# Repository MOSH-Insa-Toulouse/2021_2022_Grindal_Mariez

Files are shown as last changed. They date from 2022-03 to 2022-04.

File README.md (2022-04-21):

2021_2022_Grindal_Mariez_graphite_flex_sensor_project

# Objective of the project
The objective of the project is to design and build a PCB shield including a **low-tech graphite strain sensor** coupled to an analog electronic circuit that communicates data via a microcontroller to an Android application. The aim of this project is to get the resistance from a graphite sensor to measure a deformation, to analyze the results obtained and to describe the characteristics of the sensor in a datasheet.

# Main steps of the project
   [1. Graphite sensor conception](#1-graphite-sensor-conception)\
   [2. Electrical conception and simulation on *LTSpice*](#2-electronic-conception-and-test-on-ltspice)\
   [3. PCB conception and printing](#3-pcb-conception-on-kicad)\
   [4. Arduino code](#4-arduino-code)\
   [5. Application ANDROID](#5-apk-application)\
   [6. Test bed](#6-test-bed)\
   [7. Datasheet](#7-datasheet)\
   [8. Limits](#8-limits)

# 1. Graphite sensor conception
The first step is to make the graphite sensor with paper and a pencil. Pencil cores and lead mines used in mechanical pencils consist of a mixture clay and tiny scales of graphite that can slide on top of each other. The sensor outline is printed on a piece of thick printing paper, and the remaining work is simply to cut it out and fill in the dotted "U" shape with a pencil, as shown on the image below. 
<p align="center"> 
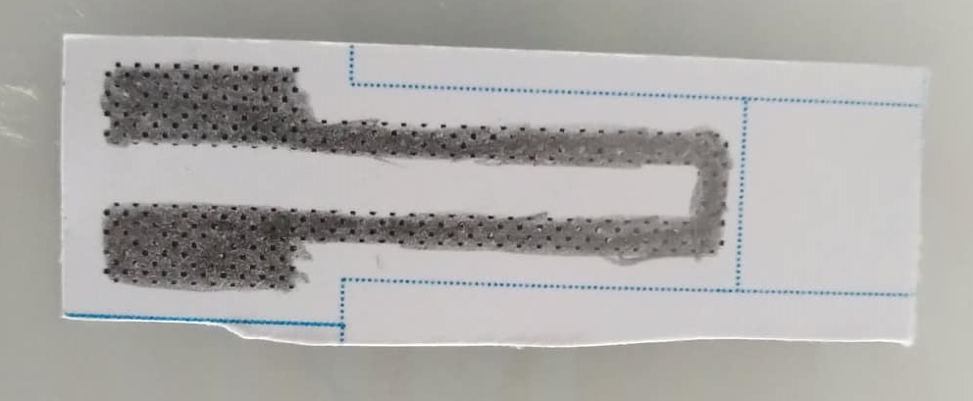
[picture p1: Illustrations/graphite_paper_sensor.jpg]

    
The upside is that is allows to adjust the amount of graphite by adding or erasing the pencil mark containing graphite. The downside is the difficulty of reproducing the same sensor with the same graphite layer thickness and density of graphite. An additional problem regarding graphite is presented below.

<div align="center">    
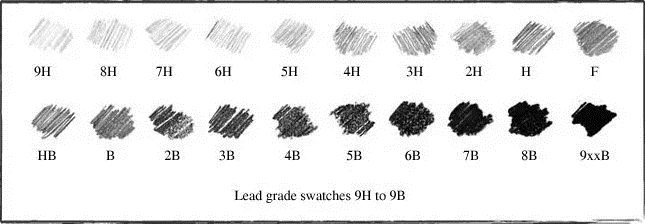
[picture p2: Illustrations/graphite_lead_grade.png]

   
**Graphite grading scale problem**
    
<div align="left"> 
    
There exists different graphite grading scales, with the numerical scale and the HB scale the two most widely used. The HB scale goes from 9B to 9H, “H” to indicate a hard pencil and “B” to designate the blackness of the pencil’s mark, indicating a softer lead and a higher proportion of graphite.
    
The problem when trying to reproduce a sensor is the lack of a specific industry standard for the darkness of the mark to be left within the HB or any other hardness grade scale. That implies that a HB pencil from one brand will not necessarily leave the same mark as a HB pencil from another brand. Most manufacturers set their own internal standards for graphite hardness grades and some differences are regional. For example in Japan, consumers tend to prefer softer darker leads, so an HB lead produced in Japan is generally softer and darker than an HB from European producers.
    
Specifying the exact product and manufacturer in addition to the graphite grading can increase the reproductibilty of the sensor.
> This project uses graphite from BIC Criterium 550 pencils with the gradings 6B, 4B, B, H and 3H. Special STEIN HB lead mines from Pentel is also used. STEIN stands for "Strongest Technology by Enhanced SiO2 Integrated Network" and have a 10 % denser core than an average HB lead mine. This can result in a different resistance range than a normal HB pencil despite applying it the same way with the same thickness etc.

# 2. Electronic conception and test on *LTSpice*
The second step is to build the electrical circuit adapted to our case. Strain sensor is a passive sensor and needs a conditionner. The output signal od the sensor is very low and can be easily interfered by noise (from the circuit or external noise). The aim of this part is to chose the good components to have the good filters and amplifiers. We also have to take into account the chracteritic of the arduino uno card we are gonna use:
* Resolution 10 to 12 bits (1024 à 4096 points)
* Full scale (VRef) : 1.1 V to 5.0 V
* Max source impedance 1 kOhm to 10 kOhm
* Max sampling frequency 15 kHz to 2.4 MHz
 
Graphite sensor is supplied by 5 V and gives resistance values between 20 MΩ and 100 MΩ. Direct measurement of a 100 nA current does not seem feasible. We have to amplifiy the signal and to filter it.
The final electrical circuit chosen is the following:
<p align="center">
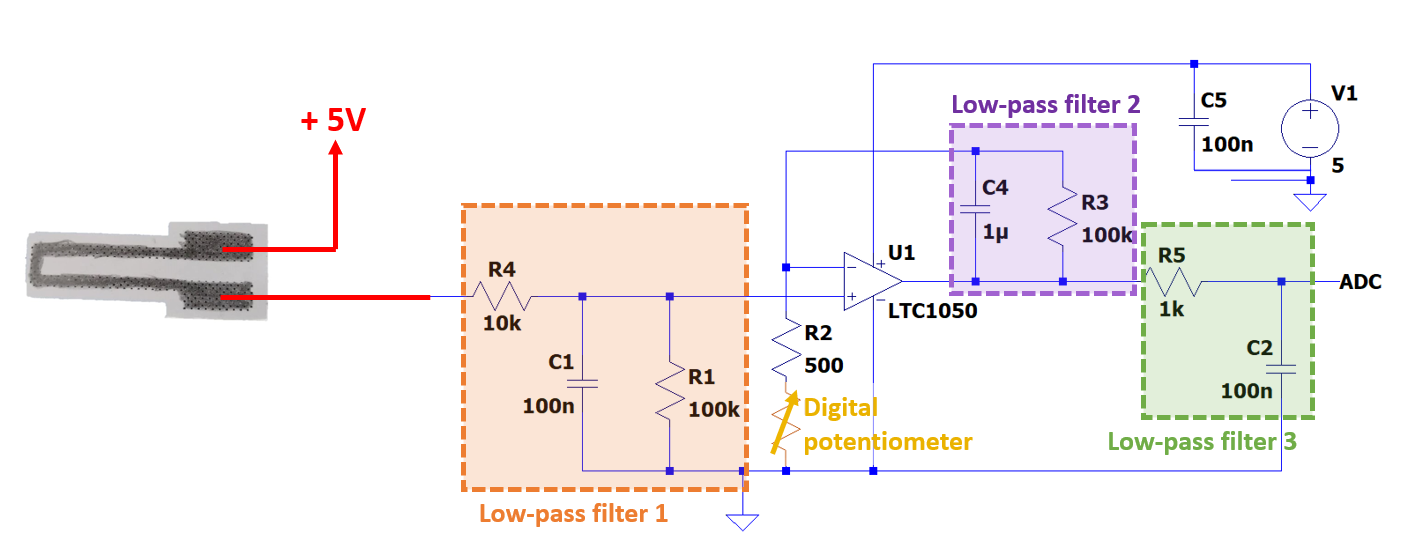
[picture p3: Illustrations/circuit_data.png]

 
### Role of different components:
> R5 at the input protects the operational amplifier against electrostatic discharges (ESD), and together with C1 makes up a filter for voltage noises
> 
> C1 with R1 makes up a filter for the current noise
>
> R2 is replaceable, in order to allow an adaptaion of the full scale range (digital potentiometer)
>
> C4 with R3 makes up the active filter
>   
> C2 with R6 makes up the passive output filter
>   
> C3 filters out the power supply noise
>   
> The digital potentiometer MCP41050 can change the gain and adapt it to the resistance value from the graphite sensor. Resistance of the digital potentiometer can vary between 330 Ω and 50k Ω based on datasheet. 
 
### Sensor resistance calculation:
<p align="center">
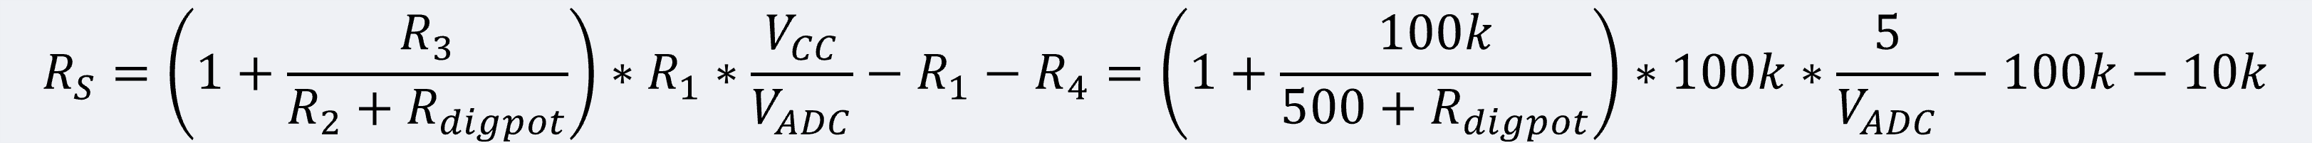
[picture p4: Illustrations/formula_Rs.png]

 
### Low-pass filters
> For each electrical stage, we can simulate the cuttoff frequency by putting the capacity of each filter at zero:
> * Low-pass filter 1 (C4 = C2 = 0) : 16 kHz\
>      To select signals with frequency less than 10*1.5kHz (sample frequency of the arduino card) to respect Shannon criteria
> * Low-pass filter 2 (C1 = C2 = 0) : 2,1 kHz\
>      To filter noises from sector of the power supply at 50 Hz
> * Low-pass filter 3 (C1 = C4 = 0) : 1,6 kHz\
       To filter global external noises of voltage and current
 
### Main characteristics of the electrical circuit
> Global gain: from 3.13 to 127.9
>
> Global attenuation of a 50 Hz current noise: 100 dB or 10e5
>
> Offset of the LTC1050 is about 5 µV wich is acceptable because much lower than the voltage measured to ouputs of the resistance R1 of 10 mV (and the maximum offset voltage drift is about 0.05 μV/°C).

### Simulations on *LTSpice*
> Simulations on LT-Spice allowed us to:
> * To check the operation in nominal conditions
> * To check the operation in nominal conditions
> * To accept the impact of the LTC1050C amplifier offset
> * To accept the impact of the amplifier input current
> * To find the cuttoff frequency of each low-pass filter stage
> * To find the global attenuation of a 50 Hz current noise
> * To find the global attenuation of a current noise occurring at the aliasing limit frequency
>
> To check all these points, we did differents simulations:
> * In transient conditions, with a pulse signal from the sensor
> * In AC conditions, to see attenuation, gain and cuttoff frequencies
> * In transient conditions, with AC voltage generator to simuate 50 Hz noise.
> * In transient and AC conditions with resistance of the digital potentiometer varying from 1 kΩ to 15 kΩ (step of 1 kΩ) to see the influence of this component on ccircuit response.
<div align="center"> 
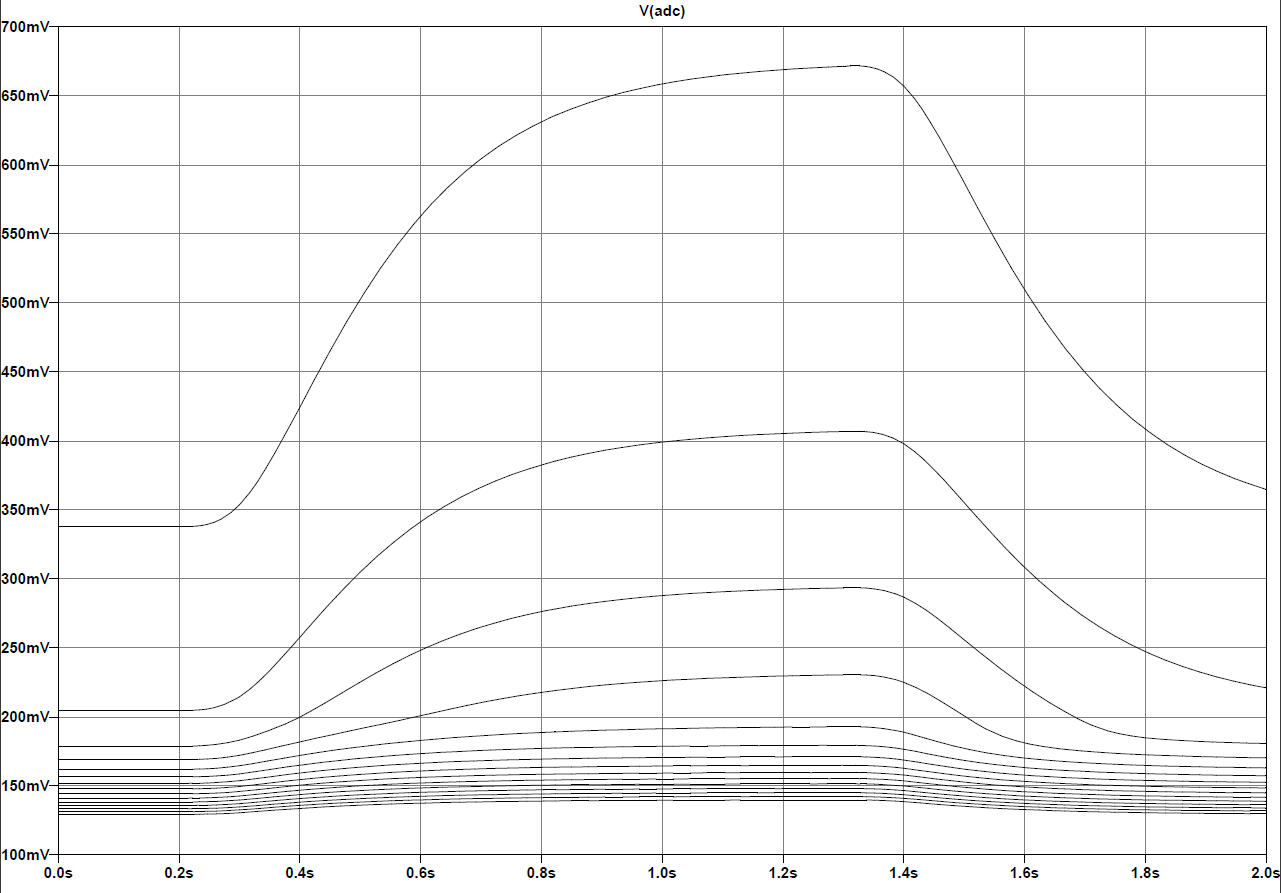
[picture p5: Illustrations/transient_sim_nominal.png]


**Transient simulation with R2 varying between 1 kΩ to 15 kΩ**
 
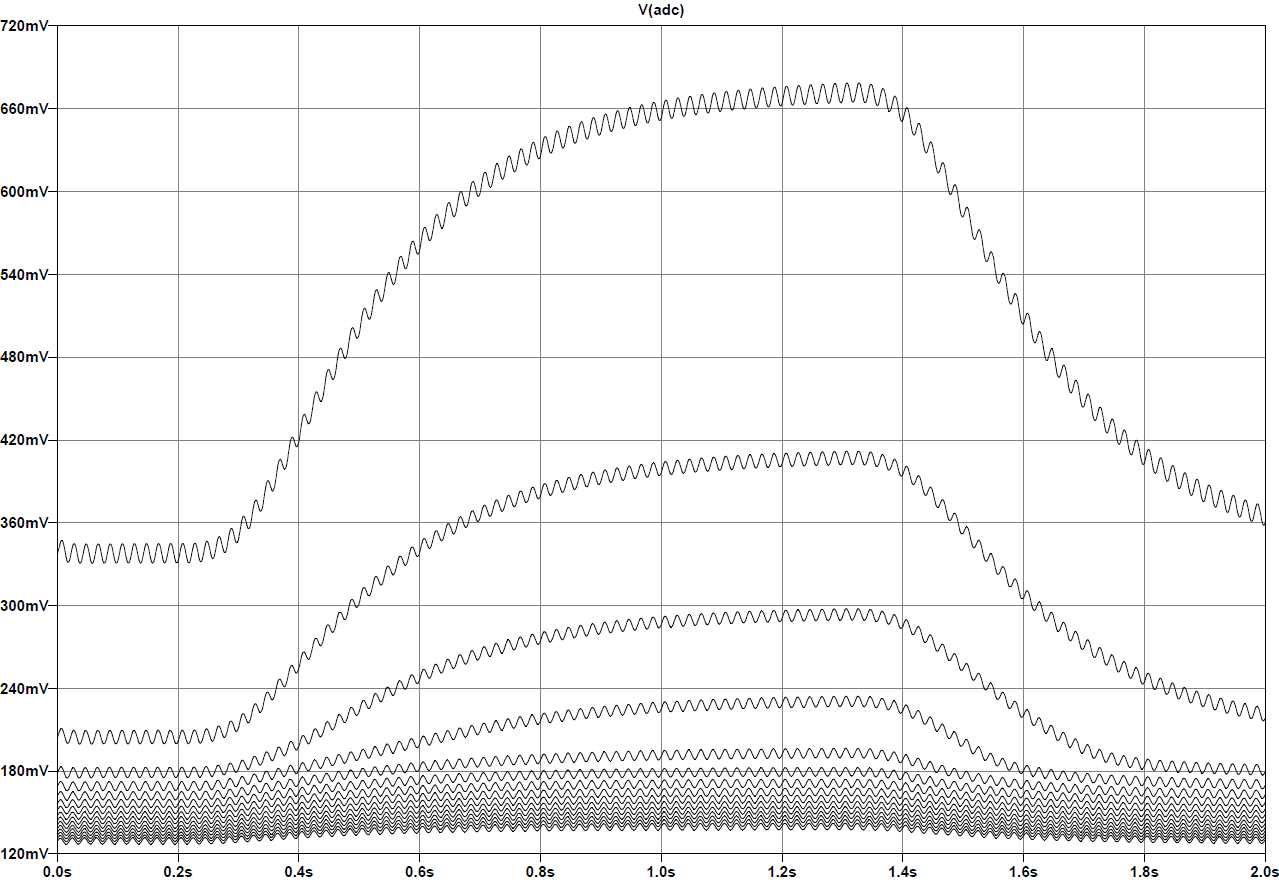
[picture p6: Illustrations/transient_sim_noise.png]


   **Transient simulation with with R2 varying between 1 kΩ to 15 kΩ and noise at 50 Hz (oscillations)**
   <div align="left">   

> The digital potentiometer has a strong influence on electrical circuit. The gain is modified, but not into a linear way with potentiometer variation. The more the resistance is high, the less is the gain, and the worse is the output signal (see [Limits](#8-limits) section)

The folder 
   [Electrical simulations on LT-Spice](https://github.com/MOSH-Insa-Toulouse/2021_2022_Grindal_Mariez/tree/main/Electrical%20simulations%20on%20LT-Spice) 
   contains the LT-Spice files used into different simulations. 

# 3. PCB conception on _KiCad_
Once the electrical circuit is done, we have to make the PCB conception to get the final circuit. First, we did the schematic in *KiCad*. Then, we build the PCB plane by adding the references and dimensions of each components. The final step is to print the PCB card with different processes.
Circuit conception was made on *KiCad*. 
### Circuit schematic on *KiCad*
> The electrical circuit was made in KiCad. All pins and connections are established. For each components, we have to associate the print. For LTC1050, rotary encoder, digital potentiometer and OLED screen, we have to create our own print in our own library. The schematic is made from a model with Arduino Uno shield to have directtly the right pins and the good dimensions of the card.
>  
<p align="center">
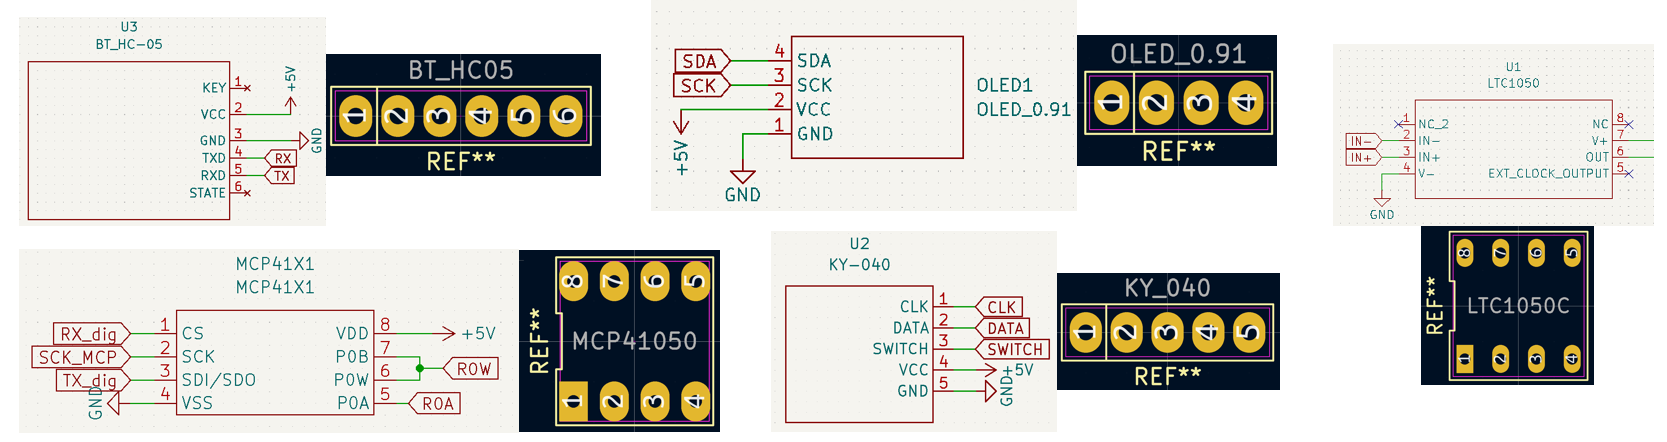
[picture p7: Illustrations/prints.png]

    
### PCB conception on _KiCad_
> After doing the schematic, we draw the PCB with the previous dimensions :
> * Track length = 0.9 mm
> * Isolation width = 0.7 mm
> * Pad dimensions for OLED, Bluetooth module and rotary encoder = 2 mm * 2.5 mm
> * Drill size for OLED, bluetooth module, rotary encoder, AOP and digital potentiometer = 1 mm
> * Pad size for AOP and digital potentiometer = 1.8 mm * 2.5 mm
> * Drill size for resistances and capacities = 2 mm
> * Pad size for resistances and capacities = 0.8 mm
> For each component, we have to find the print associated or to make it into a new libary (for rotary encoder, OLED screen, LTC1050 and digital potentiomter). After placing the components in the optimal way, we trace the wires and make the ground plane.
> 
<p align="center">
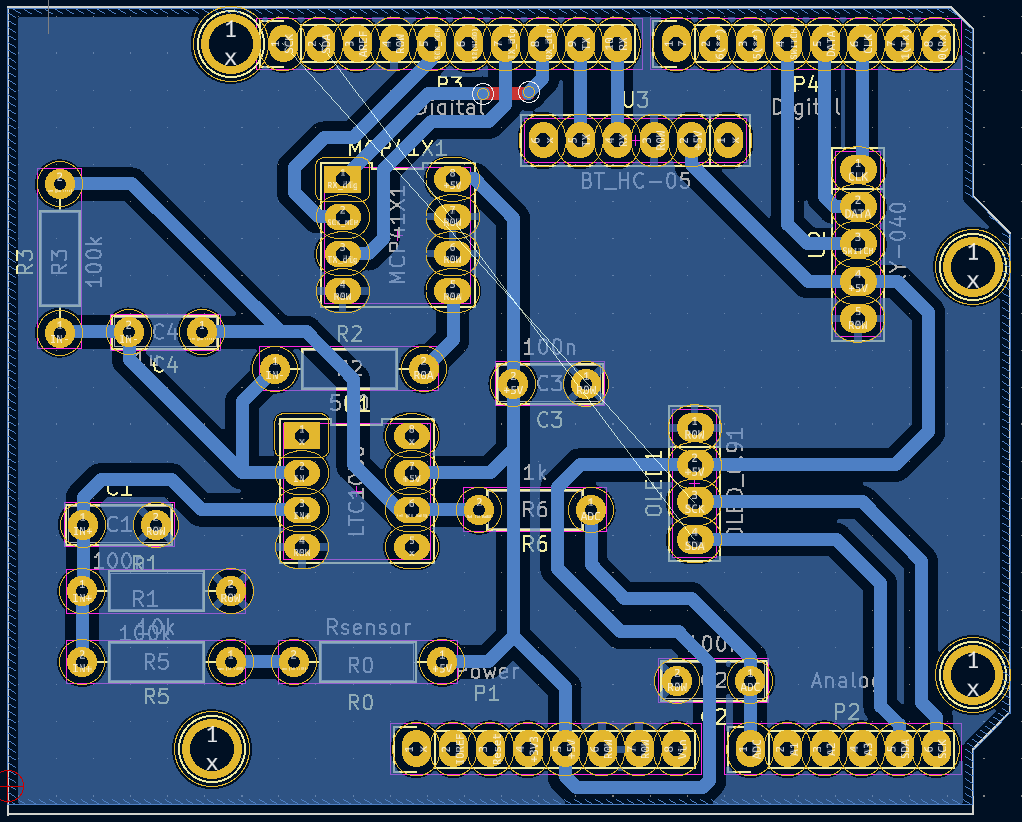
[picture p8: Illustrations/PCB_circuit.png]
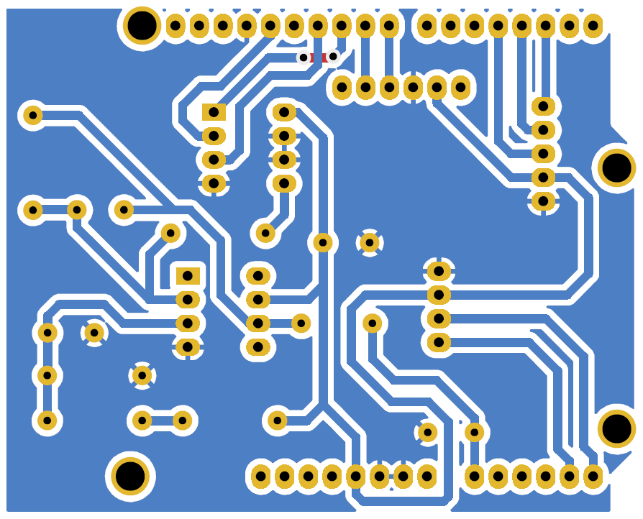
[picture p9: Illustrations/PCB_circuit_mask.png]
 

### PCB 3D visualisation  
> 
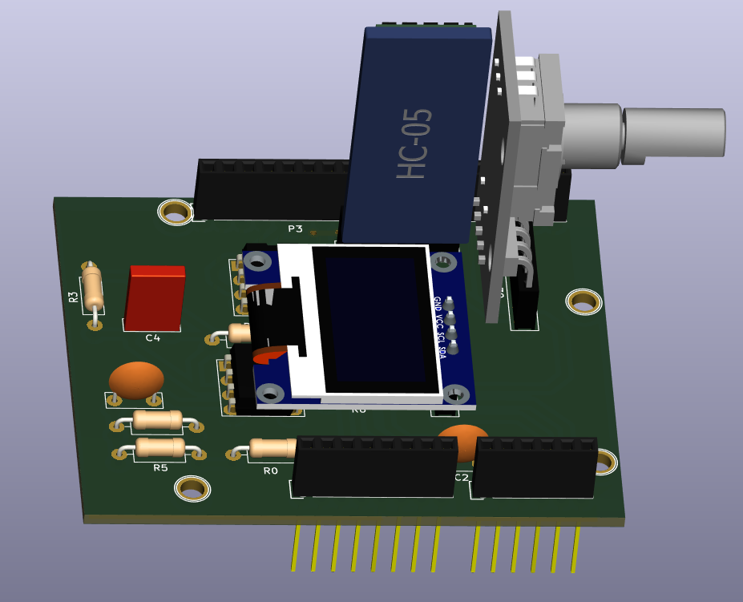
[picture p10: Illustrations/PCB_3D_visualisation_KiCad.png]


> A 3D visualisation is possible and allowed us to well arrange components placement without spatial conflict. 

All *KiCad* files are in the folder [Projet2022_grindal_mariez_pcb](https://github.com/MOSH-Insa-Toulouse/2021_2022_Grindal_Mariez/tree/main/Projet2022_grindal_mariez_pcb)
   section.

### PCB printing processes
> Mask printed on transparent film (PCB plan from KICAD) 
>
> The mask is placed on a plate of copper convered with photo-sensitive film. The mask and the plate are insolated with UV. The black part of the mask protects the photo-sensitive resin from UV, and the clear zone of the mask reveals copper beacause photo-sensitive resin reacts with UV.
>
> PCB plate is washed with a developper solution (oxydied water) that reveals the PCB circuit
>
> PCB plate is placed in oxyde bath to remove the unwanted copper not protected by photo-sensitive zone left.
>
> PCB is washed and left to dry.

<div align="center"> 
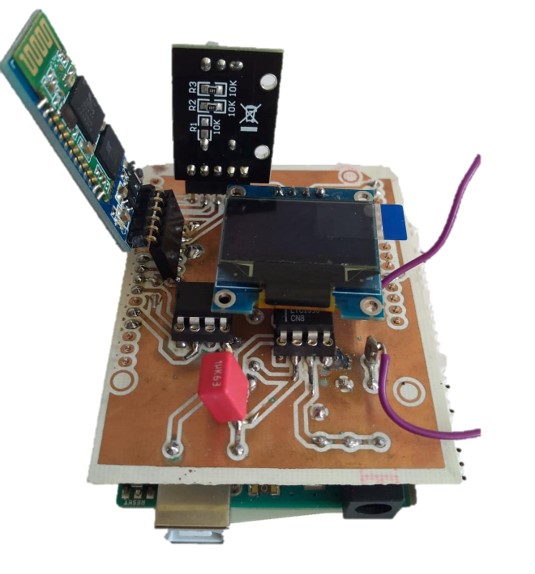
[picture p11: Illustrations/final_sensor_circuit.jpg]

   
**Final PCB circuit with all components and modules. The two wires (at right, in purple) are  \
   connected to the two pads of the graphite sensor with clamps.**
<div align="left"> 
    
# 4. Arduino code
### Improvement potential for Arduino code
> Make the code run faster and more smoothly by optimizing menu management code. This can be done by decreasing the lines of code for the OLED display and assure the switch button on the rotary encoder, which is not connected to an interrupt pin, is detected regardless of the speed of the executing loop.  The number of variables in use for the menu, submenu and blocking the rotary encoder when needed should be reduced. Suboptimal solutions to ensure the screen is refreshed correctly can be improved upon.
>
> Decrease the time interval between two measurements, currently at 700 ms, to see how fast it can measure and decrease response time.
    
### General structure of Arduino code
>The Arduino code (.ino) is written in C++ with an addition of special methods and functions.
The main text editing program used for this project is the Arduino Integrated Development Environment (IDE). It has a clean and simple interface with the option of showing a serial monitor and a serial plotter. The serial monitor is useful for checking the outcoming bytes from the board to the digital potentiometer MCP41050 and communication with the APK application via the Bluetooth module HC-05.
    
### Libraries used 
> SoftwareSerial.h for defining serial ports on specific pins, here used with the Bluetooth module and digital potentiometer.
>
> Adafruit_GFX.h and Adafruit_SSD1306.h for the I2C OLED display SBC-OLED01.
>
> Wire.h contain the definitions for I2C pins used to communicate with the OLED display.
>
> SPI.h is used to communicate with SPI devices, with Arduino as the master device. The Serial Peripheral Interface (SPI) is a synchronous serial data protocol and is used with the digital potentiometer.

### The Arduino code is divided into four parts:
>The first lines contain inclusions (#include) of libraries, definitions (#define), which is a C++ component that allows to give a name to a constant value before the program is compiled, and declarations of global variables.
>    
>The setup() function, which initializes and sets the initial values, is executed only one time after powering on the Arduino board. 
In this case, the mode of pins on the board are initialized with pinMode(), and digitalWrite() is used to turn on the pullup resistors for the rotary encoder KY-040. Data transfer through serial ports, SPI, SoftwareSerial and Serial, is enabled.
>    
>The loop() function is the main part and runs continuously after the setup until the reset button is pressed or the power supply is cut.
    It is far from optimized and contain a lot of if-statements. First it checks to detect a change in the switch button, then checks if the APK application has asked for measurement data or an updated Rcal value to update the gain. Then it does a measurement if the interval requirement is met. The last part of the loop is a mix of rotary encoder and OLED display to make the menu and submenu options work. 
>  
>The last part is constituted of definitions of the functions used in the loop function. Six functions are defined. 
>   * The first function reads the analog pin connected to the sensor called readSensor() and returns the voltage in the range 0–5 V. 
>   * Two functions manages the digital potentiometer, setPot() and potSwiper(). setPot() changes dig. pot. position and updates Rcal and gain. potSwiper() uses setPot() and takes a float as input, with the goal to land on approximately the right voltage by running through the positions to find an adequate resistance value. 
>   * The OLEDstartup() function is simply the startup screen sequence, lasting around two seconds.
>   * The last functions doEncoderA() and doEncoderB() is attached to interrupts on both pins for the rotary encoder and includes debouncing, ensuring a rapid and accurate response to manual rotation of the encoder. The variable maxRot ensures a circular list regardless of scrolling through the menu or manually adjusting the gain.

Arduino code is available in the [Arduino code](https://github.com/MOSH-Insa-Toulouse/2021_2022_Grindal_Mariez/tree/main/Arduino%20code)
   section.
  
# 5. APK application
The APK application, working on Android smartphones, is made with the free web application integrated development environment MIT App Inventor.The app communicates over Bluetooth with the HC-05 module mounted on the Arduino shield, and allows to measure and trace resistance and voltage over time.
Main features:
* Display measured voltage and resistance numerically and traced as a function of time
* Update gain if modified on the shield
* Save measured data points in a text file found in the paths "/savedRfile.txt" and "/savedVfile.txt"
    
<p align="center"> 
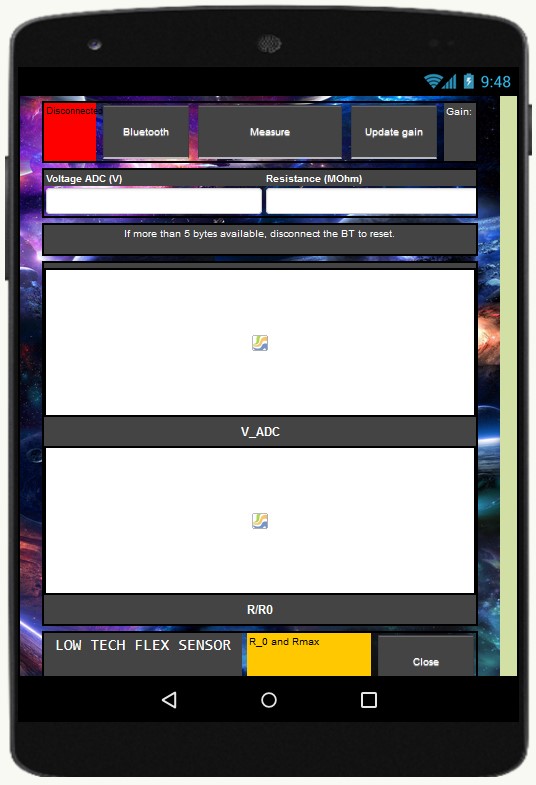
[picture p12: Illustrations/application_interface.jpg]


The application folders .apk and .api are  available in the [Application](https://github.com/MOSH-Insa-Toulouse/2021_2022_Grindal_Mariez/tree/main/Application)
   folder.
 
# 6. Test bed
The six sensors were tested under compressive and tensile deflection on cylindrical objects with a constant diameter. The test bed consisted of seven cylindral objects with each a diameter ranging from 7 cm to 1,15 cm. The contact surface was covered in paper to minimize interactions between the object and the graphite layer on the sensor under compressive deflection.

### Test procedure
> The sensor was connected to the shield with two alligator clips. Voltage measurements indicated if the start voltage was near the extreme values of the range 0-5 V, indicating signal saturation in case of very high voltage and no current flowing in case of 0 V. Saturation of the signal was handled by choosing the "set gain" option in the menu to automatically adjust the gain to start at around 1 V. No signal was fixed by applying more graphite on the dotted area of the sensor.
>
> The R0 at zero derformation was measured when the sensor was pressed flat.
>
> Each sensor was first tested under tensile deflection, that is the graphite facing away from the curvature, with the assumption that the compressive deflection is more damaging to the sensor. The tensile deflection increases the distance between the graphite layers and decreases the measured voltage. The measurements were done in the order of decreasing diameter, starting with the smallest deformation to bend the paper sensor as little as possible to avoid detoriation.
>
> Graphite was reapplied on top of the old layer and a new R0 was measured when pressed flat.
> The same procedure was repeated for the compressive deflection with the sensor laying on a flat surface graphite layer up and bent upwards around the object while pressing the object gently downwards close to the edge of the table where the alligator clips were aligned. To avoid smearing of the graphite layer, especially for the 4B and 6B pencils, minimal friction was ensured between the sensor and the paper covered object. It is possible that smearing would have a minimal impact because the layer applied was thick. The measurements were done in the order of decreasing diameter, starting with the smallest deformation. 
>
> For compressive deflection, sudden drops in voltages occured for some of the sensors when repedately bending around the smallest objects and inducing large deformations. In those cases, graphite was reapplied on top of the old layer, a new R0 was measured when pressed flat and a new measurement series was conducted starting with the largest object.
    
# 7. Datasheet
Datesheet is providing the main characteristics and technical specifications of the strain sensor. It is in the folder [Datasheet](https://github.com/MOSH-Insa-Toulouse/2021_2022_Grindal_Mariez/tree/main/Datasheet)
   of the repository. 

# 8. Limits
   Is important to notice the limits of the sensor and the innacuracy of the test measures. Here are main points to be studied or solved:
   * The digital potentiometer MCP41050 is perfectly adapted to the graphite sensor. It would be better to have a sensor with a resistance variation between 10 Ω to 15 Ω, as the MCP41010 from *Microchip* for example.
   * The mapping from 8 bits to 10 bits in arduino code may lead to a resolution loss, so we lose in quality for the signal. 
   * We need a switch button to interrupt in case of problems
   * Regarding test bed, we are never sure of the amount of deposited graphite and it is not uniform. Also, the graphite quantity variation is not linear with pencils changing. Finally, paper is damaged after several compression/tension, so the measures are never similar

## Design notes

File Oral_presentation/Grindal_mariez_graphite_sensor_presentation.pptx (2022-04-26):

## Capteur de déformation low-tech

GRINDAL Ruth E.
MARIEZ Edith
INSA TOULOUSE – Génie Physique

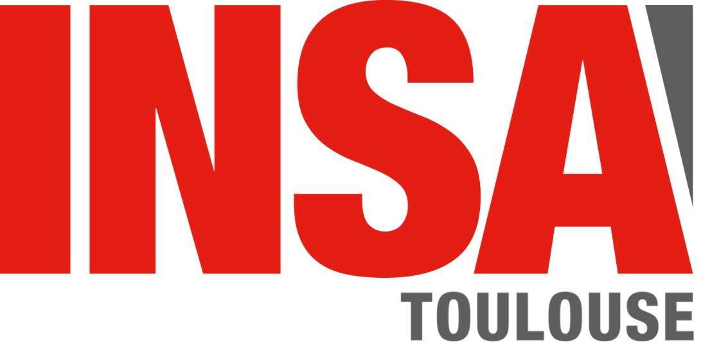
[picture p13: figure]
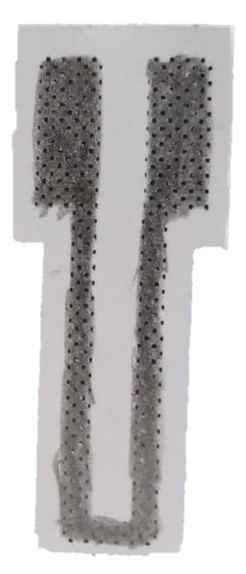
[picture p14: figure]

## Théorie de la percolation dans les systèmes granulaires

Compression

- Molécules proches
- Tension VADC augmente
- Resistance RS diminue

Etat nominal

Traction

- Molécules éloignées
- Tension VADC diminue
- Resistance RS augmente

## Conditionneur

Capteur passif

Solution : conditionneur

Fréquence de coupure du filtre 1 | 16 Hz
Fréquence de coupure du filtre 2 | 2.1 Hz
Fréquence de coupure du filtre 3 | 1.6 kHz
Gain total | 3.13 to 127.9
Atténuation du bruit à 50 Hz | 100 dB

Besoin d’amplifier et de filtrer le signal

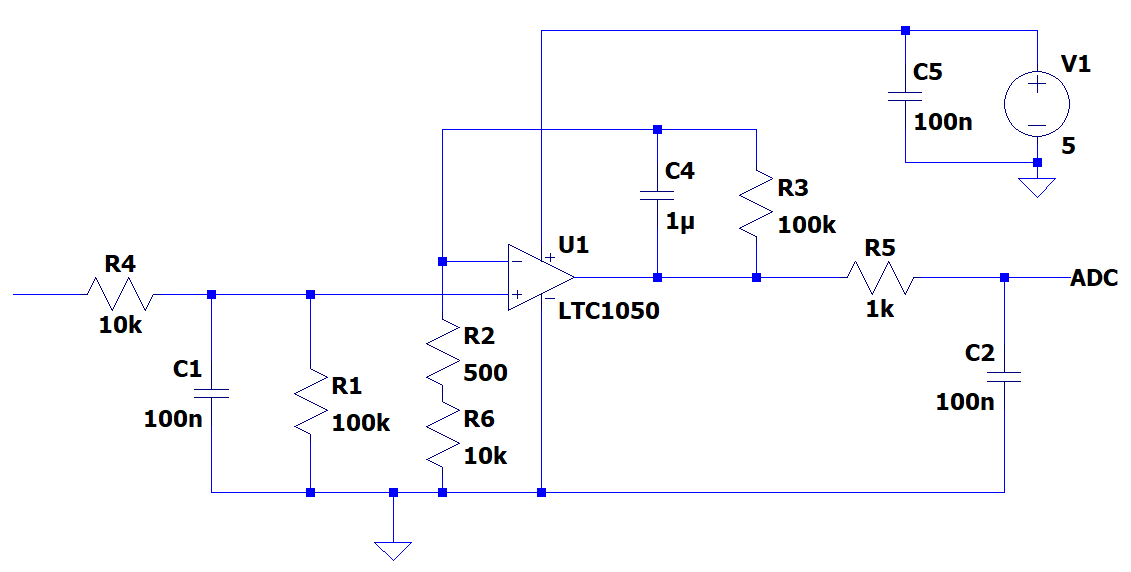
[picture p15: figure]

R_S =(1+(R_3)/(R_2 +R_(digpot)))∗R_1 ∗(V_(CC))/(V_(ADC))−R_1 −R_4 =(1+(100k)/(500+R_(digpot)))∗100k∗5/(V_(ADC))−100k−10k

Filtre 2 : passe-bas actif

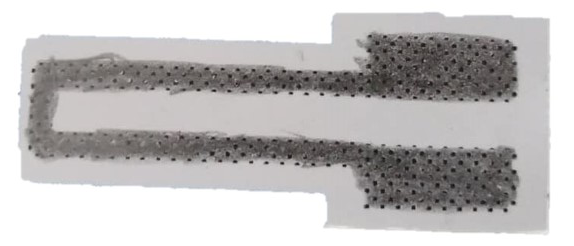
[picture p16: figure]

+ 5V

Filtre 1 : passe-bas passif

Filtre 3 : passe-bas passif

Potentiomètre digital

## Conception du PCB


## Android application

Connection bluetooth
Affichage numérique de la tension VADC et de la résistance RS
Deux graphes pour tracer les valeurs en temps réel
Bouton de mesure qui réinitialise les graphes et reçoit de nouveau des octets du module
Gain actualisé après calibration avec le PCB
Communication terminée avec le circuit quand l’application est fermée

Et bilde som inneholder tekst, overvåke, svart, sølv Automatisk generert beskrivelse

## Banc de test

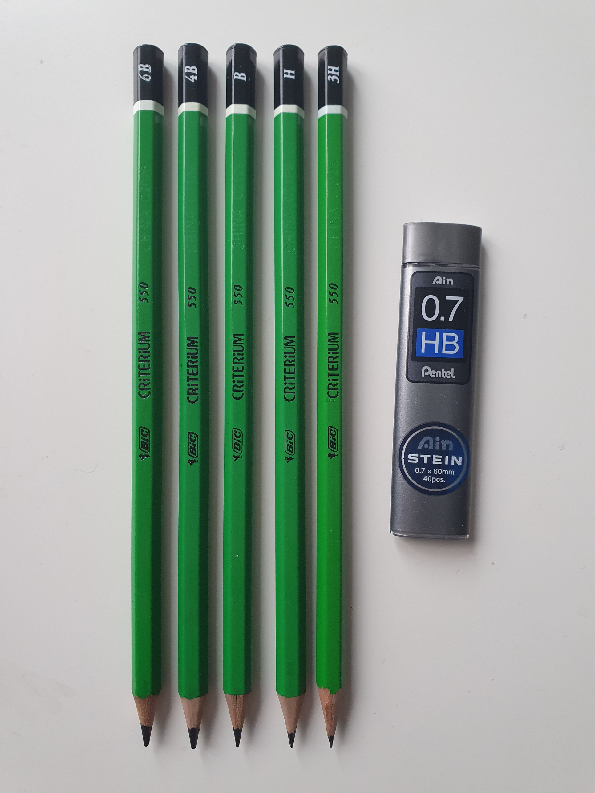
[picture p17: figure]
Et bilde som inneholder tekst, skrivesaker, brevhode, blyant Automatisk generert beskrivelse

Device | Measured R range (MΩ) (**) | Gain (to start at ≈ 1 V)
3H | 150 - 1100 | 127,9
H | 150 - 1100 | 127,9
HB(*) | 1,1 – 2,2 | 3,74
B | 5,4 - 13 | 18,62
4B | 0,9 – 2,7 | 3,13
6B | 0,4 – 3,2 | 3,13

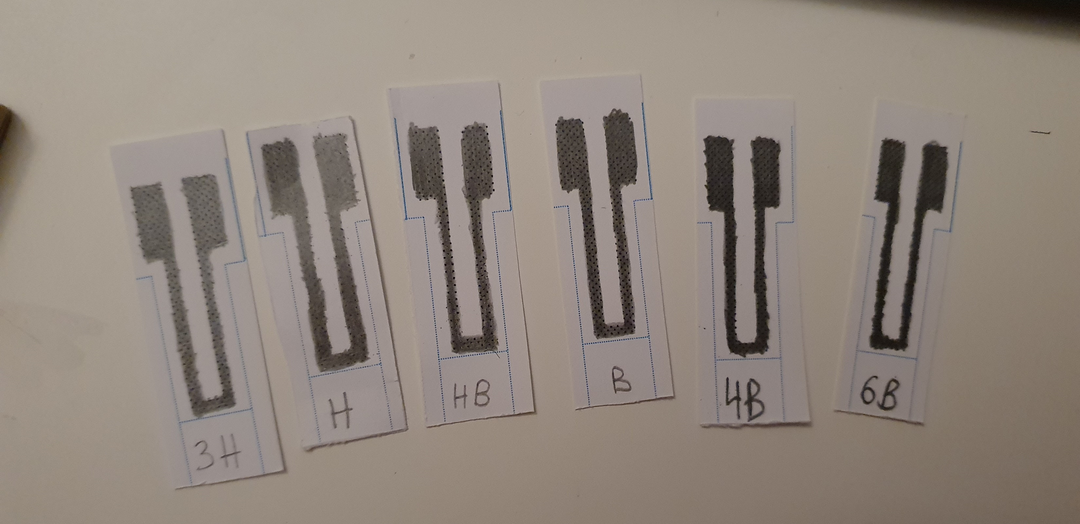
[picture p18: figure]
Et bilde som inneholder tekst, tavle Automatisk generert beskrivelse

Diameter in cm for cylindrical test objects | Deformation
7,03 | 0,004
5,38 | 0,006
3,98 | 0,008
3,59 | 0,008
1,91 | 0,016
1,75 | 0,017
1,16 | 0,026

- Approximation of deformation: ε (e/2) ≈ e/(2∗R)
e: paper thickness
R: radius of curvature
- No industrial standard for HB scale
- Pencil manufacturers set their own internal standards for graphite hardness grades and overall quality of the core, some differences are regional. In Japan, consumers tend to prefer softer darker leads; so an HB lead produced in Japan is generally softer and darker than an HB from European producers.

(*) 10 % denser lead mine with a ceramic cell structure, higher graphite density than other HB pencils
(**) low resolution with high gain and 10 to 8 bit mapping

## Résultats

## Limites du capteur

Convertisseur CAN:
Perte de résolution dans le passage de 10 bits à 8 bits Offset sur la sortie, qui augmente avec Rpotdig qui augmente

Arduino code:
Besoin d’un réponse plus rapide Résolution pas suffisante: 10 bits sur l’écran OLED et 8 bits sur l’application Pas d’interruption sur le bouton SWITCH

Mesures de test:
Quantité de graphite non homogène Quantité de graphite non linéairement variable en fonction des crayons Papier déformé après plusieurs mesures

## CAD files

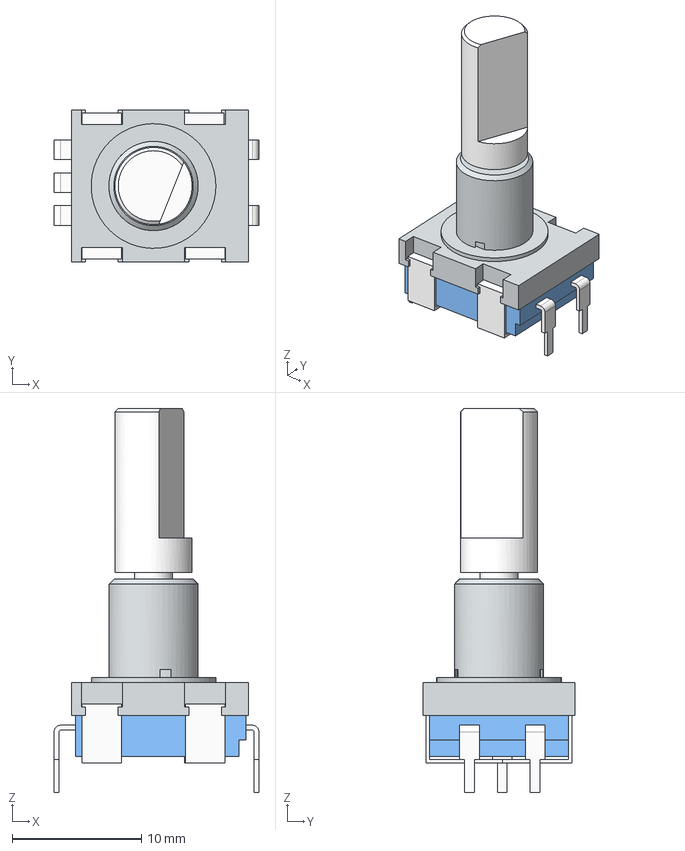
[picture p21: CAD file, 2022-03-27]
Projet2022_grindal_mariez_pcb/rotary-encoder-1.snapshot.8/rotary encoder step files/Step Files/Rotary Encoder without pcb Assembly.stp
15.8 x 11.8 x 29.7 mm
mtg flange
body_encoder
pins_encoder body_2 x 5
shaft_encoder

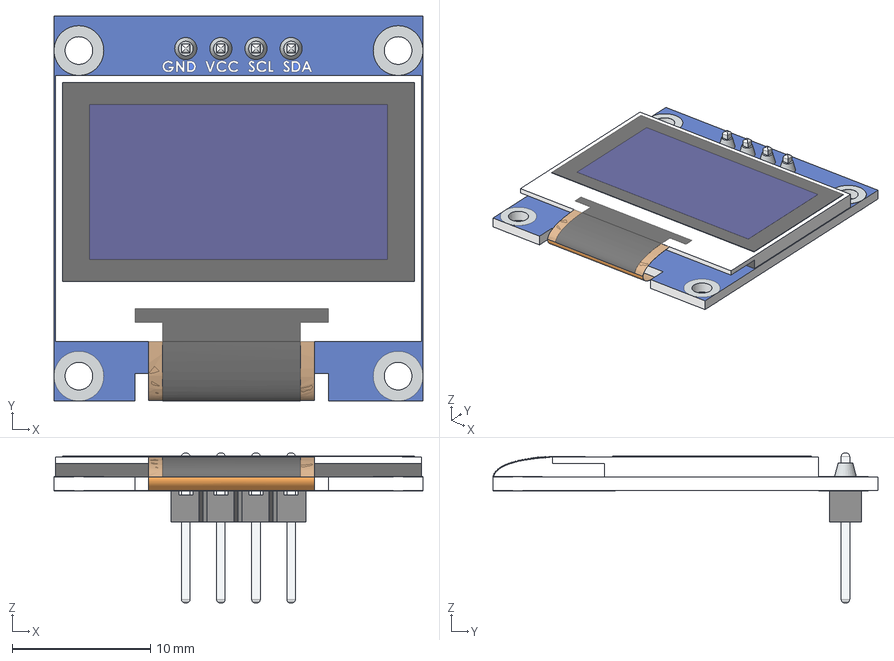
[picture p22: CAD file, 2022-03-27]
Projet2022_grindal_mariez_pcb/display-oled-ssd1306-de-0-96-1.snapshot.6/OLED-128x64-0.96.step
26.7 x 27.9 x 10.8 mm

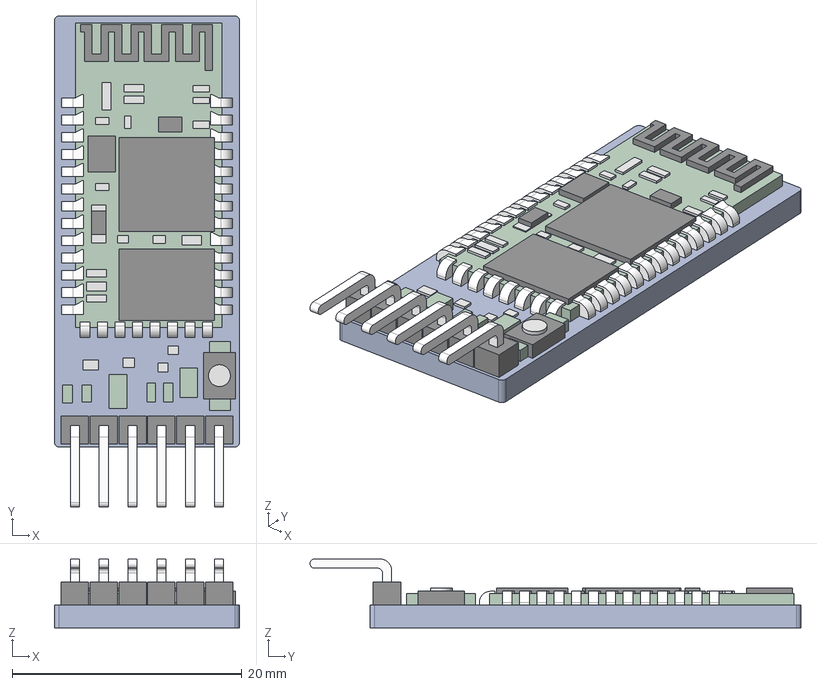
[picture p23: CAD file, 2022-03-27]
Projet2022_grindal_mariez_pcb/hc-05-bluetooth-module-2.snapshot.1/HC_05 Blue Tooth Module.stp
16.1 x 42.7 x 6.00 mm

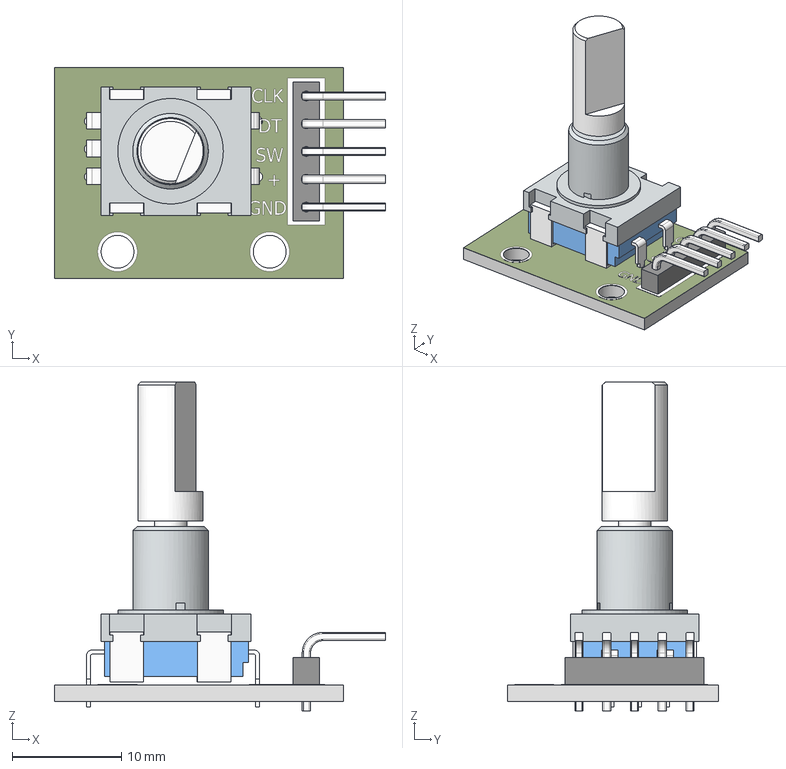
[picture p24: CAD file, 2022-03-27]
Projet2022_grindal_mariez_pcb/rotary-encoder-1.snapshot.8/rotary encoder step files/Step Files/rotary encoder_chesr_2013.stp
30.3 x 19.3 x 30.1 mm

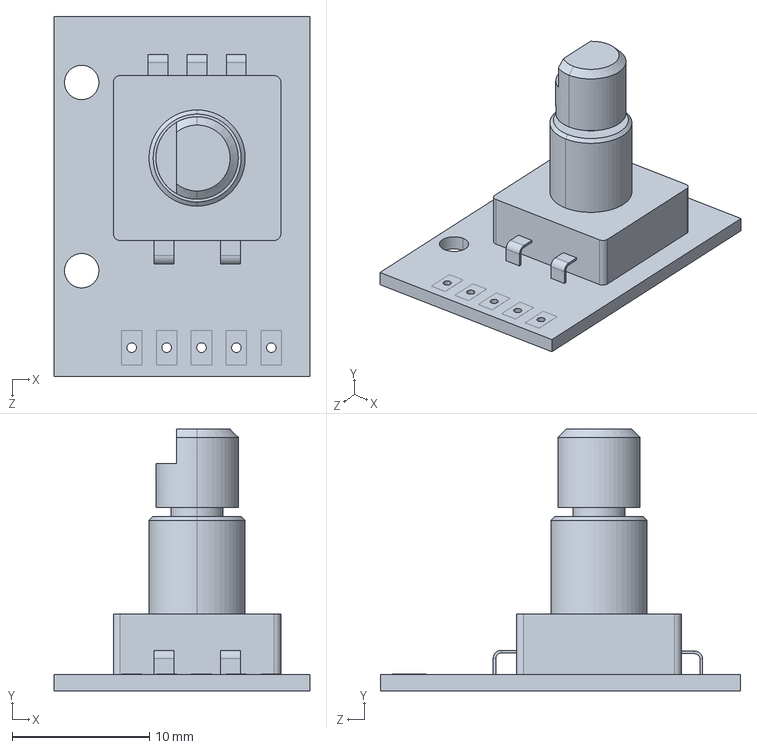
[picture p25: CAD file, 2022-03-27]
Projet2022_grindal_mariez_pcb/rotary-encoder-ky-040-1.snapshot.3/Encoder KY-040.STEP
18.6 x 19.1 x 26.2 mm

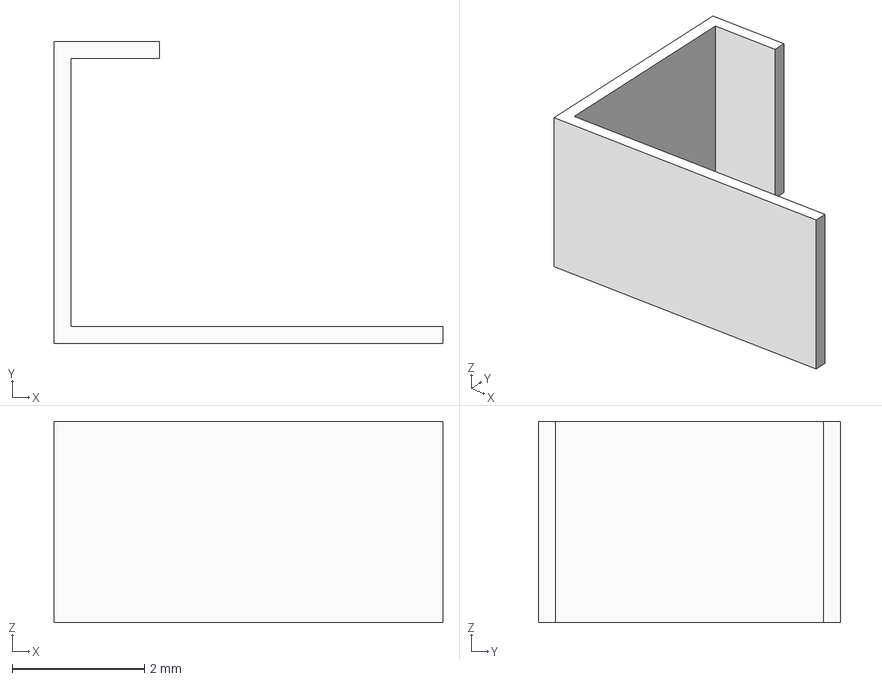
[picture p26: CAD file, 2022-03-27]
Projet2022_grindal_mariez_pcb/rotary-encoder-1.snapshot.8/rotary encoder step files/Step Files/body_2.stp
5.89 x 4.57 x 3.05 mm

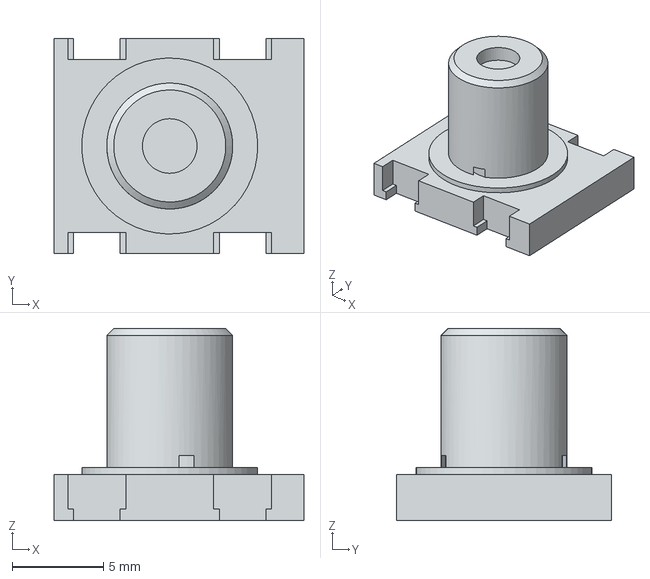
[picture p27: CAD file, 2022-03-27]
Projet2022_grindal_mariez_pcb/rotary-encoder-1.snapshot.8/rotary encoder step files/Step Files/mtg flange.stp
13.7 x 11.8 x 10.5 mm

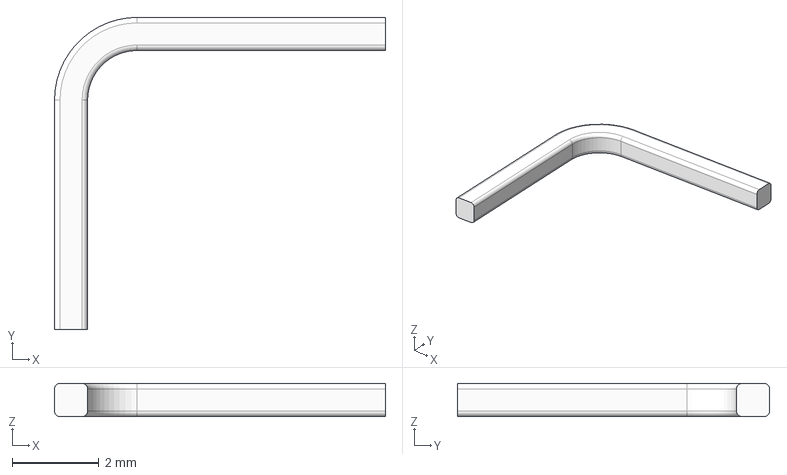
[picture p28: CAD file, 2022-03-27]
Projet2022_grindal_mariez_pcb/rotary-encoder-1.snapshot.8/rotary encoder step files/Step Files/90d pin_header.stp
7.62 x 7.19 x 0.762 mm

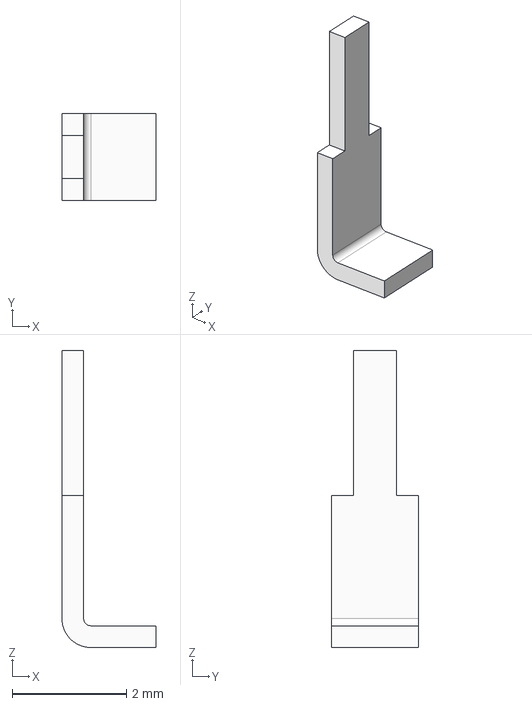
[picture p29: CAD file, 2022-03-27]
Projet2022_grindal_mariez_pcb/rotary-encoder-1.snapshot.8/rotary encoder step files/Step Files/pins_encoder body_2.stp
1.65 x 1.52 x 5.21 mm

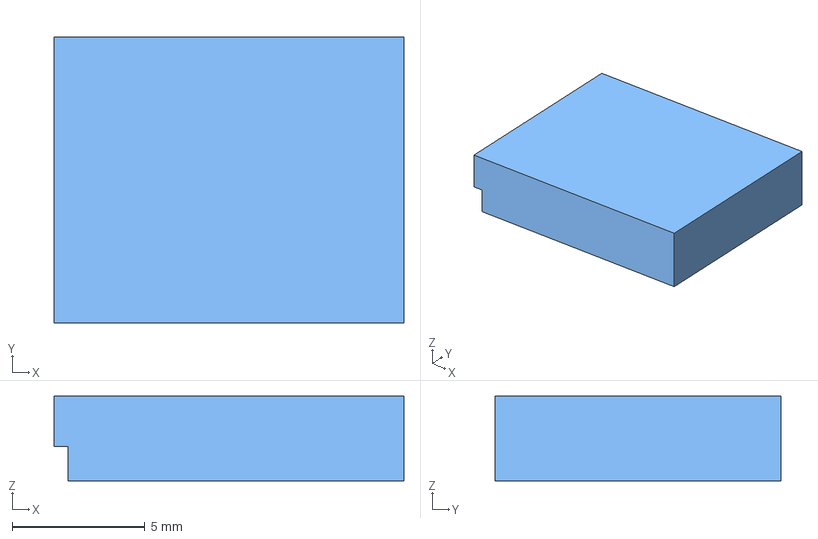
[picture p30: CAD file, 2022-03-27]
Projet2022_grindal_mariez_pcb/rotary-encoder-1.snapshot.8/rotary encoder step files/Step Files/body_encoder.stp
13.2 x 10.8 x 3.20 mm

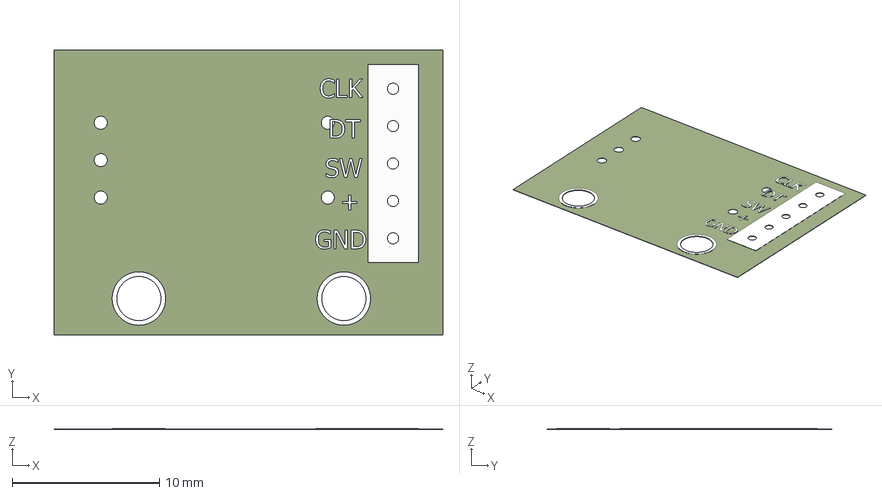
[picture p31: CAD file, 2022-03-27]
Projet2022_grindal_mariez_pcb/rotary-encoder-1.snapshot.8/rotary encoder step files/Step Files/decal_encoder.stp
26.4 x 19.3 x 0.0508 mm

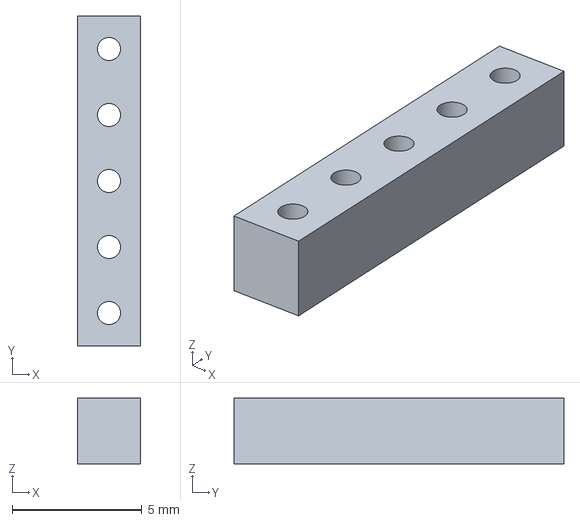
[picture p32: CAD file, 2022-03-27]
Projet2022_grindal_mariez_pcb/rotary-encoder-1.snapshot.8/rotary encoder step files/Step Files/5 pin header.stp
2.41 x 12.7 x 2.54 mm

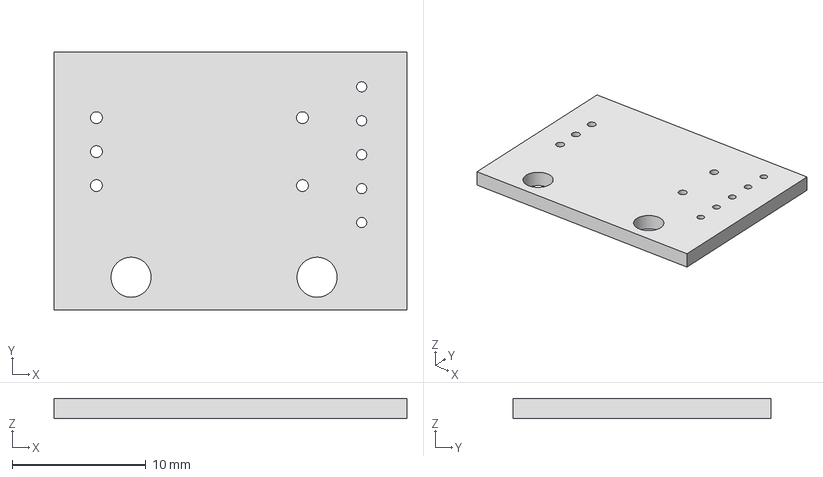
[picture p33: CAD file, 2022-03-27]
Projet2022_grindal_mariez_pcb/rotary-encoder-1.snapshot.8/rotary encoder step files/Step Files/pcb.stp
26.4 x 19.3 x 1.52 mm

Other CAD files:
Projet2022_grindal_mariez_pcb/hc-05-bluetooth-module-2.snapshot.1/HC_05 Blue Tooth Module.ipt
Projet2022_grindal_mariez_pcb/rotary-encoder-1.snapshot.8/Rotary Encoder/5 pin header.ipt
Projet2022_grindal_mariez_pcb/rotary-encoder-1.snapshot.8/Rotary Encoder/90d pin_header.ipt
Projet2022_grindal_mariez_pcb/rotary-encoder-1.snapshot.8/Rotary Encoder/OldVersions/mtg flange.0001.ipt
Projet2022_grindal_mariez_pcb/rotary-encoder-1.snapshot.8/Rotary Encoder/OldVersions/pins_encoder body_2.0001.ipt
Projet2022_grindal_mariez_pcb/rotary-encoder-1.snapshot.8/Rotary Encoder/OldVersions/pins_encoder body_2_2.0001.ipt
Projet2022_grindal_mariez_pcb/rotary-encoder-1.snapshot.8/Rotary Encoder/OldVersions/rotary encoder_chesr_2013.0010.iam
Projet2022_grindal_mariez_pcb/rotary-encoder-1.snapshot.8/Rotary Encoder/body_2.ipt
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

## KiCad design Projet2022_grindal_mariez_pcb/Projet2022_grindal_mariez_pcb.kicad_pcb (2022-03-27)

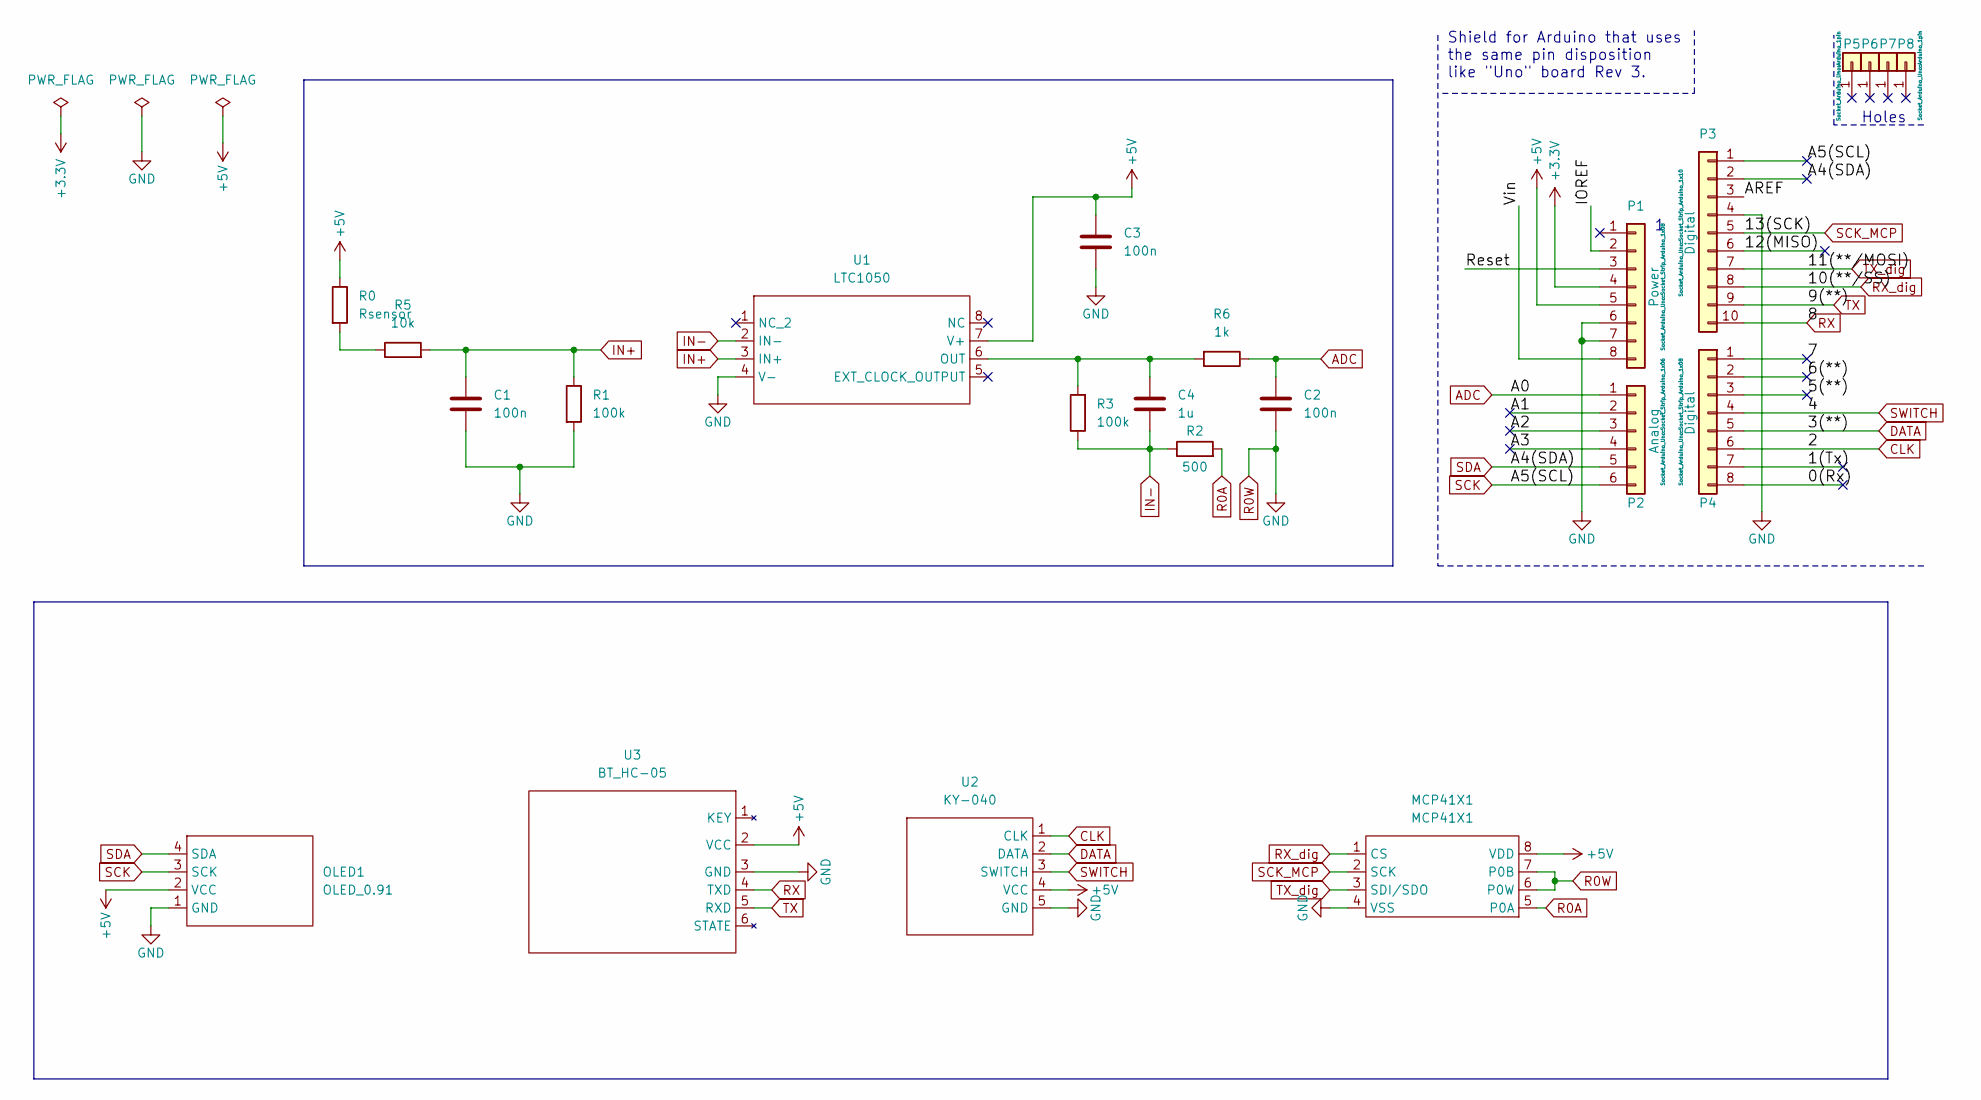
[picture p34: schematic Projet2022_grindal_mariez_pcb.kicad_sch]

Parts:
C1, C2, C3: 100n; C_Disc_D7.0mm_W2.5mm_P5.00mm
C4: 1u; C_Rect_L7.0mm_W2.0mm_P5.00mm
MCP41X1: MCP41X1; MCP41050
OLED1: OLED_0.91
P1: Power; Socket_Strip_Arduino_1x08
P2: Analog; Socket_Strip_Arduino_1x06
P3: Digital; Socket_Strip_Arduino_1x10
P4: Digital; Socket_Strip_Arduino_1x08
P5, P6, P7, P8: CONN_01X01; Arduino_1pin
R0: Rsensor; R_Axial_DIN0207_L6.3mm_D2.5mm_P10.16mm_Horizontal
R1, R3: 100k; R_Axial_DIN0207_L6.3mm_D2.5mm_P10.16mm_Horizontal
R2: 500; R_Axial_DIN0207_L6.3mm_D2.5mm_P10.16mm_Horizontal
R5: 10k; R_Axial_DIN0207_L6.3mm_D2.5mm_P10.16mm_Horizontal
R6: 1k; R_Axial_DIN0207_L6.3mm_D2.5mm_P7.62mm_Horizontal
U1: LTC1050; LTC1050C
U2: KY-040; KY_040
U3: BT_HC-05; BT_HC05

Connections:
+3V3: P1.4
+5V: C3.2, MCP41X1.8 (VDD), OLED1.2 (VCC), P1.5, R0.1, U1.7 (V+), U2.4 (VCC), U3.2 (VCC)
/0(Rx): P4.8
/1(Tx): P4.7
/5(**): P4.3
/6(**): P4.2
/7: P4.1
/12(MISO): P3.6
/A1: P2.2
/A2: P2.3
/A3: P2.4
/AREF: P3.3
/IOREF: P1.2
/Reset: P1.3
/Vin: P1.8
ADC: C2.1, P2.1, R6.1
CLK: P4.6, U2.1 (CLK)
DATA: P4.5, U2.2 (DATA)
IN+: C1.1, R1.1, R5.2, U1.3 (IN+)
IN-: C4.2, R2.1, R3.1, U1.2 (IN-)
unnamed: C4.1, R3.2, R6.2, U1.6 (OUT)
unnamed: R0.2, R5.1
R0A: MCP41X1.5 (P0A), R2.2
R0W: C1.2, C2.2, C3.1, MCP41X1.4 (VSS), MCP41X1.6 (P0W), MCP41X1.7 (P0B), OLED1.1 (GND), P1.6, P1.7, P3.4, R1.2, U1.4 (V-), U2.5 (GND), U3.3 (GND)
RX: P3.10, U3.4 (TXD)
RX_dig: MCP41X1.1 (CS), P3.8
SCK: OLED1.3 (SCK), P2.6, P3.1
SCK_MCP: MCP41X1.2 (SCK), P3.5
SDA: OLED1.4 (SDA), P2.5, P3.2
SWITCH: P4.4, U2.3 (SWITCH)
TX: P3.9, U3.5 (RXD)
TX_dig: MCP41X1.3 (SDI/SDO), P3.7

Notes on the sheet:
Holes
Shield for Arduino that uses the same pin disposition like "Uno" board Rev 3.

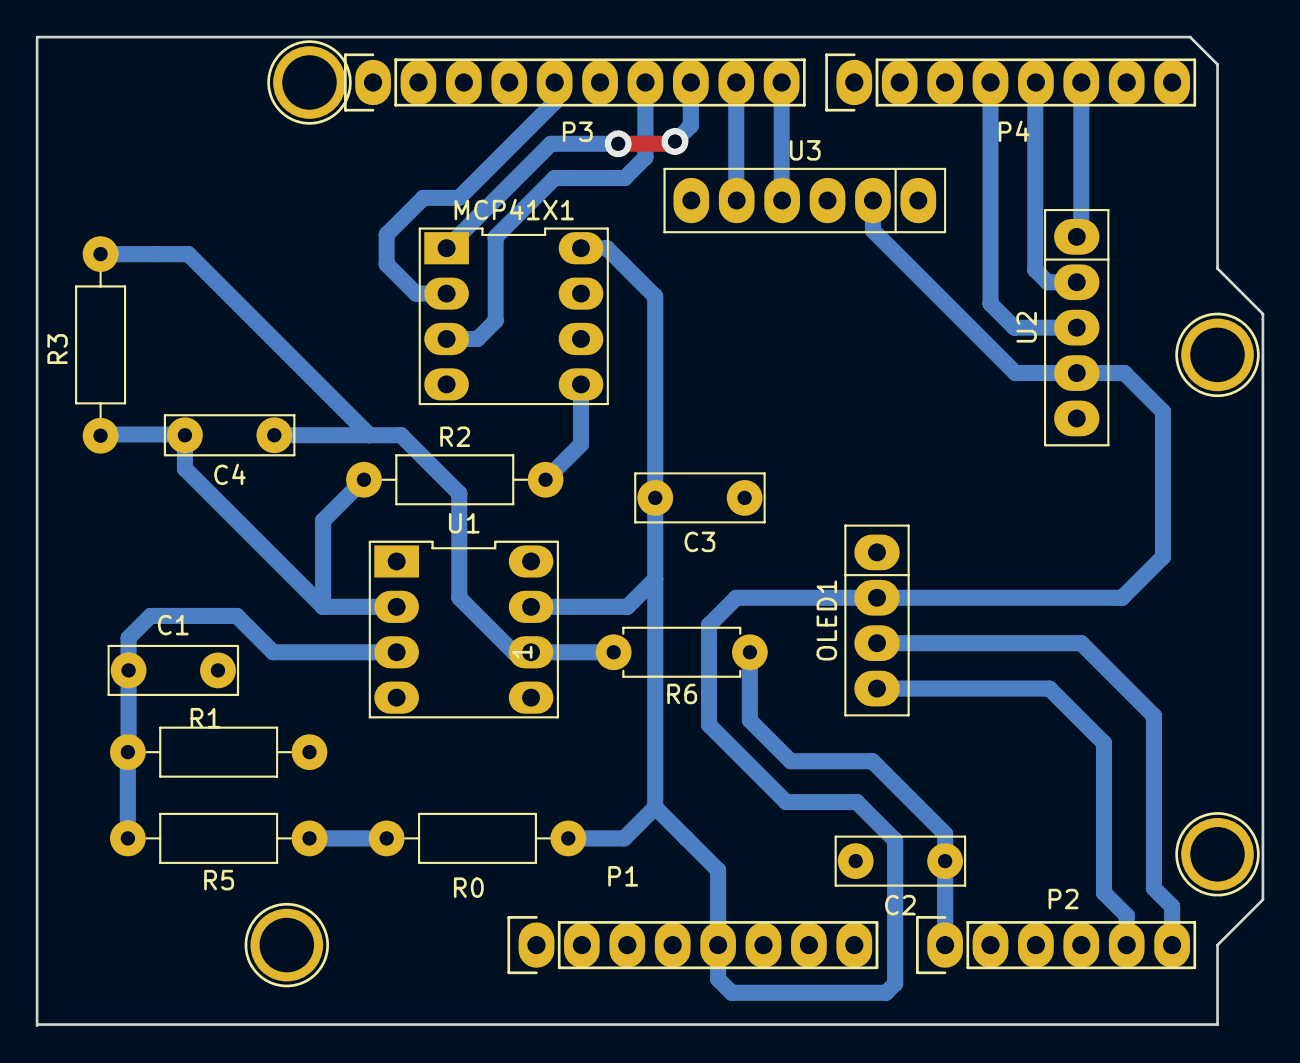
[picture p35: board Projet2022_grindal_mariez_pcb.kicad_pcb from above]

Board: 2 copper layers, 68.6 x 55.3 mm, 23 parts (0 on the bottom side), 18 nets.

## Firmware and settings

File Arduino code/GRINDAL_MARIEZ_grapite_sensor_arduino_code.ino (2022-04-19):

#include <SoftwareSerial.h>
#include <Adafruit_GFX.h>
#include <Adafruit_SSD1306.h>
#include <Wire.h>                // pins for I2C are defined by Wire library

// digital potentiometer
int pos = 255;
const byte csBarPin = 10;       // MCP42050 chip select pin
const int  maxPositions = 256;  // wiper can move from 0 to 255 = 256 positions
const long rAB = 46300;         // 46300 Ohm with multimeter between 5 and 6
const byte rWiper = 320;        // 320 ohm measures when in position 255
const byte pot0 = 0x11;         // pot0 addr // B 0001 0001
const byte pot0Shutdown = 0x21; // pot0 shutdown // B 0010 0001 
#define csBarPin 10
#define siPin 11

// signal amplifier
const int flexPin = A0;         // pin connected to voltage divider output
const float VCC = 5.0;          // voltage at Ardunio 5V line
float Rs = 0.0;
const float R5 = 10000.0;
const float R1 = 100000.0;
const float R3 = 100000.0;
float Rcal=rWiper+468;
float gain = 1+R3/Rcal;

unsigned long previousMillis = 0; // count milliseconds from last measurement
const long interval = 700;        // time between two measurements

// OLED screen
#define SCREEN_WIDTH 128         // OLED display width, in pixels
#define SCREEN_HEIGHT 32         // OLED display height, in pixels
#define OLED_RESET -1            // reset pin
#define SCREEN_ADDRESS 0x3C
Adafruit_SSD1306 OLED(SCREEN_WIDTH, SCREEN_HEIGHT, &Wire, OLED_RESET);

// rotary encoder KY-040
#define encoderPinA 2                 // right
#define encoderPinB 3                 // left
#define  switchButton 4               // switch button
volatile unsigned int encoderPos = 0; // a counter for the dial
unsigned int lastReportedPos = 1;     // change management
static boolean rotating = false;      // debounce management
int menu=0; int submenu=0;
int setGain=0; // disables menu rotation when 1
int autoCalibrate=0; // to prevent the calibration to run in a loop
int maxRot=65335; float Mohms = 0.;
int ADCin = 0; float VADC = 0.;

// interrupt service routine
boolean A_set = false;
boolean B_set = false;

// bluetooth and dig. pot. serial ports
#define rxPin 8   // connect rxPin to TX on HC-05
#define txPin 9   // // connect txPin to RX on HC-05
SoftwareSerial mySerialBT(rxPin ,txPin);
SoftwareSerial mySerialDP(csBarPin ,siPin);
byte incomingByte = 0;   // for incoming serial data
byte serialRX;    // stock the received data
volatile byte RX = 0; 
byte mode = 0; // send or receive data from the BT application

void setup() {

  pinMode(flexPin, INPUT);
  // OLED screen
  if(!OLED.begin(SSD1306_SWITCHCAPVCC, SCREEN_ADDRESS))
    while(1);
  OLEDstartup();

  // rotary encoder KY-040
  pinMode(encoderPinA, INPUT);
  pinMode(encoderPinB, INPUT);
  pinMode(switchButton, INPUT);
  // turn on pullup resistors
  digitalWrite(encoderPinA, HIGH);
  digitalWrite(encoderPinB, HIGH);
  digitalWrite(switchButton, HIGH);
  // encoder pin on interrupt 0 (pin 2)
  attachInterrupt(0, doEncoderA, CHANGE);
  // encoder pin on interrupt 1 (pin 3)
  attachInterrupt(1, doEncoderB, CHANGE);

  // dig. pot.
  SPI.begin();
  digitalWrite(csBarPin, HIGH);   // chip select default to de-selected
  pinMode(csBarPin, OUTPUT);      // configure chip select as output
  setPot(pot0, pos);

  //bluetooth
  pinMode(rxPin,INPUT);
  pinMode(txPin,OUTPUT);
  Serial.begin(9600);
  mySerialBT.begin(9600);
  mySerialDP.begin(9600);
  mySerialBT.listen();
  mySerialBT.flush();
}


void loop(){
  OLED.setTextSize(1); // measure R and V changes it to 2
  int sent = 1;        // send only 1 byte when mode == 2
  rotating = true;     // reset the debouncer

  // detect button
  if (digitalRead(switchButton) == LOW){
    menu = 1;}
  
  // BT
  if (mySerialBT.available() > 0){
    incomingByte = mySerialBT.read();
    if (incomingByte==1){
      mode = 1;}
    else if (incomingByte==2){
      sent = 0;
      mode = 2;}
    else {mode = incomingByte;}}
  
  // measurement
  unsigned long currentMillis = millis();
  if (currentMillis - previousMillis >= interval) {     
    previousMillis = currentMillis;   
    ADCin = analogRead(flexPin);
    // conversion from 10 to 8 bits
    ADCin = map(analogRead(flexPin),0,1024,0,255);  
    VADC = 5.*ADCin/256. ;
    float Rs = (1.0+R3/Rcal)*R1*(VCC/VADC)-R1-R5;
    Mohms = Rs/1000000.;  
    if (mode == 1){
      // send measurement to app
      mySerialBT.write(ADCin);}}
  
  // send dig. pot. pos to recalculate Rcal in app
  if ((mode == 2) && (sent != 1)){
    mySerialBT.write(pos);
    sent=1;}
  
  // rotary encoder and menu shown on screen
  if (lastReportedPos != encoderPos){ 
    if (submenu == 1){
      maxRot = 3;
      lastReportedPos = encoderPos;
      OLED.clearDisplay();
      OLED.setCursor(0, 0);
      switch (lastReportedPos) {
        case 0:
          OLED.println("-> MEASURE R <-");
          OLED.println("MEASURE V");
          OLED.println("AUTO CALIBRATE");
          OLED.println("SET GAIN");
          break;
        case 1:
          OLED.println("MEASURE R");
          OLED.println("-> MEASURE V <-");
          OLED.println("AUTO CALIBRATE");
          OLED.println("SET GAIN");
          break;
        case 2:
          OLED.println("MEASURE R");
          OLED.println("MEASURE V");
          OLED.println("-> AUTO CALIBRATE <-");
          OLED.println("SET GAIN");
          break;
        case 3:
          OLED.println("MEASURE R");
          OLED.println("MEASURE V");
          OLED.println("AUTO CALIBRATE");
          OLED.println("-> SET GAIN <-");
          break; }
          OLED.display();} 
    else if ((submenu == 2) && (setGain == 1)){
      maxRot = 255;
      lastReportedPos = encoderPos;
      setPot(pot0, encoderPos);
      pos = encoderPos;
      OLED.clearDisplay();
      OLED.setCursor(0, 0);
      OLED.println("Dig, pot. position: ");     
      OLED.println(encoderPos, DEC);
      OLED.print("Gain:");
      OLED.setCursor(64, 16);
      OLED.println(gain);
      OLED.print("Voltage:");
      OLED.setCursor(64, 24);    
      OLED.print(readSensor());
      OLED.display();}}
    
  // button has been pressed
  if ((menu == 1) && (digitalRead(switchButton) != LOW)){
    if (setGain == 1){setGain = 0;} 
    switch (submenu){ 
      case 0:
        OLED.clearDisplay();
        encoderPos = 0;
        submenu = 1;
        break;
      case 1:
        OLED.clearDisplay();
        submenu = 2;
        break;
      case 2:
        // problem with screen not updating after
        // exiting the R measure
        OLED.clearDisplay();
        OLED.setCursor(0,0);
        OLED.println("-> MEASURE R <-");
        OLED.println("MEASURE V");
        OLED.println("AUTO CALIBRATE");
        OLED.println("SET GAIN");
        OLED.display();
        submenu = 1;
        encoderPos = 0;
        autoCalibrate = 0;
        break;} 
    menu= 0 ;} 
  
  // menu management
  if (digitalRead(switchButton) != LOW){ 
    if ((submenu == 2) && (lastReportedPos == 3)){
      if (setGain != 1){
        OLED.clearDisplay();
        OLED.setCursor(0,0); 
        OLED.println("Please rotate to ");
        OLED.println("adjust the gain. ");
        OLED.display();
        delay(500);
        OLED.clearDisplay();
        pos=encoderPos;
        setGain = 1;}}
    else if ((submenu == 2) && (setGain != 1)){
      switch (lastReportedPos){ 
        case 0:
          OLED.clearDisplay();
          OLED.setCursor(0,0);
          OLED.setTextSize(2); 
          OLED.println("R (MOhm): ");  
          OLED.print(Mohms);
          OLED.display();
          delay(100); 
          break;
        case 1:
          OLED.clearDisplay();
          OLED.setCursor(0,0);
          OLED.setTextSize(2);
          OLED.println("VADC (V): ");
          OLED.print(VADC);
          OLED.display(); 
          delay(100);
          break;
        case 2:        
          int showPos = -1;
          if (autoCalibrate != 1){
            OLED.clearDisplay();
            OLED.setCursor(0,0);
            OLED.println("Please wait...");
            OLED.display();
            delay(100);
            showPos = potSwiper(1.1);
            OLED.clearDisplay();
            OLED.setCursor(0,0);  
            OLED.println("Dig. pot. position:");
            OLED.println(showPos);
            OLED.println("Gain: ");
            OLED.setCursor(64, 16);
            OLED.println(gain);
            OLED.print("Voltage:");
            OLED.setCursor(64, 24);
            OLED.print(readSensor());
            OLED.display();
            autoCalibrate = 1; }          
            break;}}}
} 

// --end of loop--

float readSensor(){
  int ADCin = analogRead(flexPin);
  // conversion from 10 to 8 bits
  ADCin = map(analogRead(flexPin),0,1024,0,255);  
  float VADC = 5.*ADCin/256.;
  return VADC;
}

// changes dig. pot. position and updates Rcal and gain
void setPot(int addr, int pos){
  pos = constrain(pos, 0, 255);
  digitalWrite(csBarPin, LOW);    // select chip
  //// configure target pot with wiper position
  SPI.transfer(addr);             
  SPI.transfer(pos);
  digitalWrite(csBarPin, HIGH);   // de-select chip
  Rcal = 320+468+(rAB/255)*(255-pos);
  gain = 1+R3/Rcal;          
}

// changes dig. pot. to land on approx.
// the initial voltage
int potSwiper(float init_voltage) {
  setPot(pot0, 255);
  delay(1000);
  float VADC_old = 0.;
  int pos_init=0;
  for(int i = 255; i >= 0; i--){
    pos_init = i;
    setPot(pot0, pos_init);
    // small delay to stabilize the voltage
    // after changing the dig. pot.
    delay(200);
    float VADC_new = readSensor();
    if (VADC_new <= init_voltage){
      break;}
    if (VADC_new > init_voltage){
      if ((VADC_old > VADC_new) && (VADC_old != 0.0)){
        pos_init = i-1;  
        
        setPot(pot0, pos);
        break;}}}
    pos = pos_init;
  return pos_init; 
}

void OLEDstartup(){ 
  OLED.clearDisplay();
  OLED.setTextSize(1); 
  OLED.setTextColor(SSD1306_WHITE);
  OLED.setCursor(30, 10);
  OLED.println("LOW-TECH");
  OLED.setCursor(30, 20);
  OLED.println("FLEX SENSOR");
  OLED.display();
  delay(1000);
  OLED.invertDisplay(true);
  delay(100);
  OLED.invertDisplay(false);
  delay(100);
  OLED.setTextSize(2);  
  OLED.setCursor(30, 0);  
  OLED.clearDisplay();
  OLED.print(F("Ready!"));
  OLED.setCursor(20, 25);
  OLED.setTextSize(1);
  OLED.print(F("Press to start.")); 
  OLED.display();
}

// interrupt on A changing state and debouncing
void doEncoderA(){
  // debounce
  if (rotating){delay(1);} // wait a little until the bouncing is done
  // test transition
  if (digitalRead(encoderPinA) != A_set ){ // debounce once more
    A_set = !A_set;
    // update counter + if A leads B
    if (A_set && !B_set){
      if (lastReportedPos == maxRot){
        encoderPos = 0;}
      else {encoderPos += 1;}}    
    // no more debouncing until loop() hits again
    rotating = false;}}

// interrupt on B changing state
void doEncoderB(){
  if (rotating){delay(1);}
  if (digitalRead(encoderPinB) != B_set){
    B_set = !B_set;
    //  update counter - 1 if B leads A
    if (B_set && !A_set){
      if (lastReportedPos == 0){
        encoderPos = maxRot;}
      else {encoderPos -= 1;}}
    rotating = false;}}

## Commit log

2022-04-18 Update README.md
    Description of Arduino code
2022-04-19 Add files via upload
    fix update gain in apk app
    [GRINDAL_MARIEZ_grapite_sensor_arduino_code.ino]
2022-04-21 Create adc
